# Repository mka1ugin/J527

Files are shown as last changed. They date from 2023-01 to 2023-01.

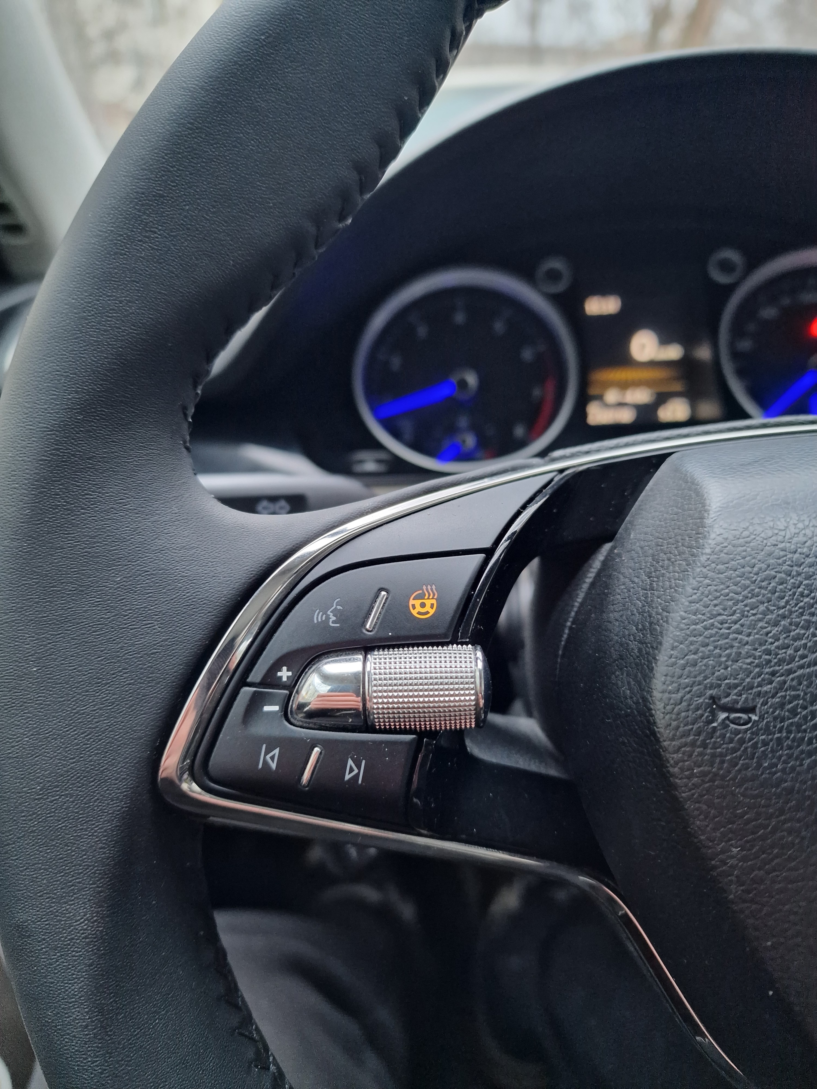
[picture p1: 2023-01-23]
result.jpg

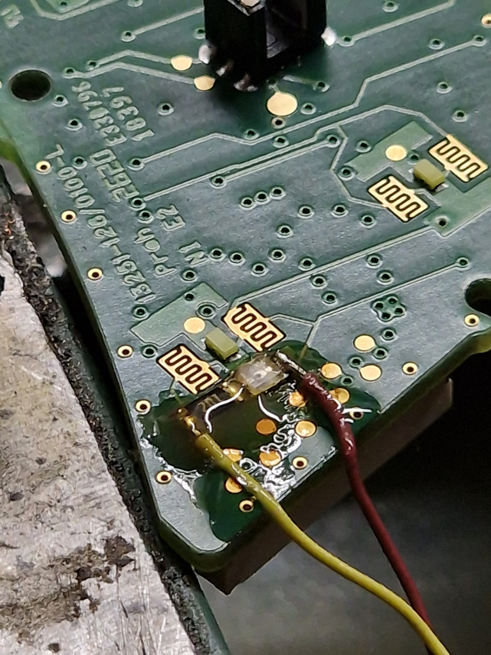
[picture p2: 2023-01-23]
heat_indication_led.jpg

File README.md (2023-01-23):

# J527
## Дополнительный контроллер для подрулевого блока 5K0953569, реализующий работу кнопки ассистентов, круиза и обогрева руля

Руль от Skoda 2021 5E3419093CVKH оборудован обогревом руля, кнопкой включения и выключения подогрева, а также кнопками быстрого вызова ассистентов и установки скорости круиз-контроля. Руль дооснащён LIN-LIN конвертером https://github.com/mka1ugin/LIN_MFSW_Adapter и установлен на VW Passat B6.
Подрулевой блок 5K0953569T доработан путём установки дополнительных шлейфов обогрева руля от блока 5Q1953569B. 
Контроллер выполнен на МК STM32F103C8T6 и реализует следующие функции:
* Управление работой обогрева руля
* Эмуляция нажатия кнопки быстрого вызова ассистентов
* Эмуляция нажатия кнопки задания скорости круиз-контроля

## Контроль обогрева руля

Сигнал нажатия кнопки обогрева руля отслеживается через LIN-шину. Нажатие кнопки включает и выключает обогрев руля. Питание на обогрев подаётся с клеммы 15 и только при включенном зажигании. Кроме того, контроллер отслеживает напряжение питания и работа возможна только при напряжении выше 12.5 В (настраивается в прошивке), т.е. при работающем двигателе. Силовой ключ VN7010A взят из блока 5Q1953569B.
Контроллер оборудован FRAM-памятью FM24CL16, в которую записывается каждое изменение состояния обогрева. Таким образом, если машина была заглушена со включенным обогревом, при следующем запуске двигателя обогрев будет включен автоматически.

## Эмуляция нажатия кнопок

Контроллер управляет двумя герконовыми реле серии EDR3. Их контактные группы включены параллельно штатным кнопкам "SET" круиз-контроля и кнопке быстрого вызова ассистентов. Контакты геркона дублируют состояние соответствующих кнопок на руле.

## Реализация

Контроллер выполнен на односторонней плате размером 50x47.5 мм и соединяется с блоком подрулевых переключателей двумя разъёмами: трёхконтактный - питание 12В и LIN-шина, и пятиконтактный - эмуляция нажатия кнопок. Также контроллер имеет два силовых четырёхконтактных разъёма - вход силового питания и выход на шлейф обогрева.render3

## Видео работы:
<p align="center">
  <a href="https://youtu.be/Oqg4uzVC5qI">youtube
</p>

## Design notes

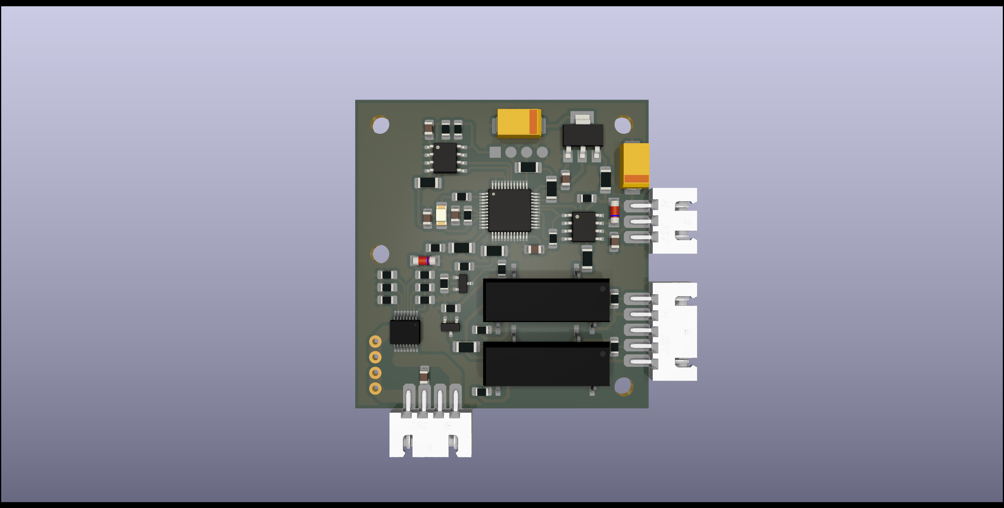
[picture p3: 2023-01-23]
HW/J527/pcb_render.png

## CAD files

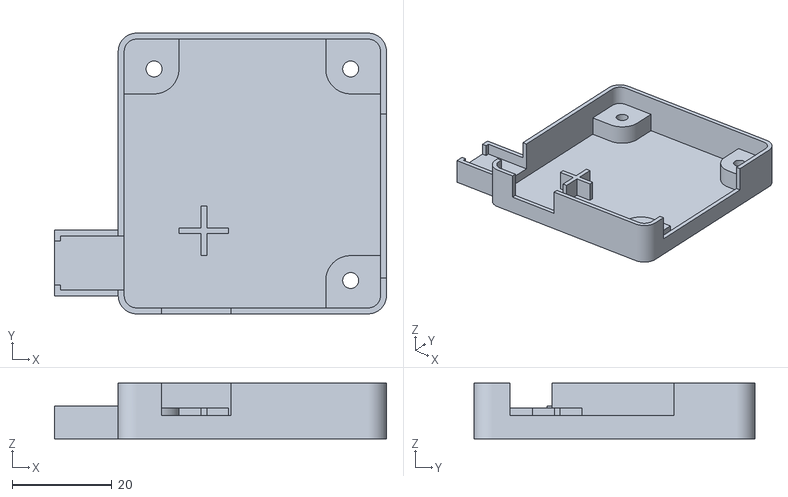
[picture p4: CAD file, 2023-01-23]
HW/J527/3Dprint/Основание.stl
66.7 x 56.4 x 11.2

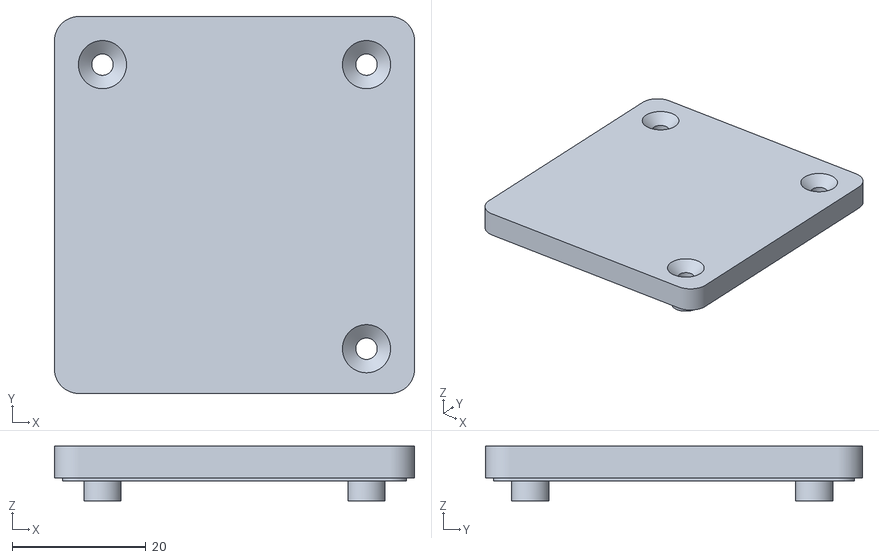
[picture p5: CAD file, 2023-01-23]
HW/J527/3Dprint/Крышка.stl
53.9 x 56.4 x 8.20

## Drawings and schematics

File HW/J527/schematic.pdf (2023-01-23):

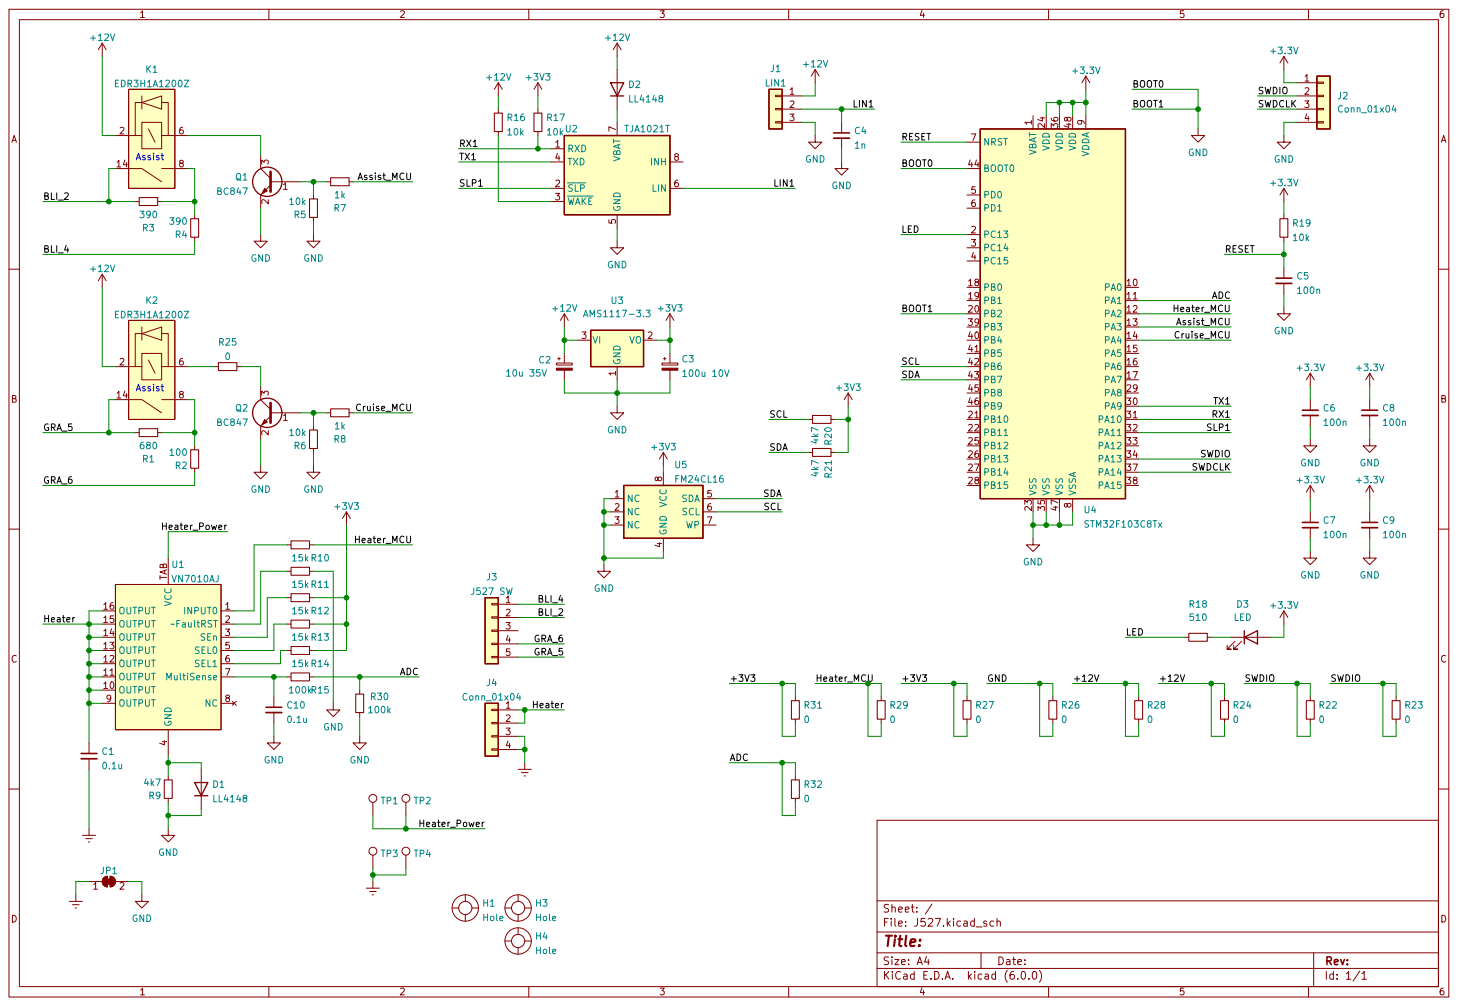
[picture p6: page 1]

1 PA0 10 PA1 11 PA2 12 PA3 13 PA4 14 PA5 15 PA6 16 PA7 17 PB0 18 PB1 19 PC13 2 PB2 20 PB10 21 PB11 22 VSS 23 VDD 24 PB12 25 PB13 26 PB14 27 PB15 28 PA8 29 PC14 3 PA9 30 PA10 31 PA11 32 PA12 33 PA13 34 VSS 35 VDD 36 PA14 37 PA15 38 PB3 39 PC15 4 PB4 40 PB5 41 PB6 42 PB7 43 BOOT0 44 PB8 45 PB9 46 VSS 47 VDD 48 PD0 5 PD1 6 NRST 7 VSSA

4 SEL0 5 SEL1 6 MultiSense 7 NC 8 OUTPUT 9 VCC TABU1VN7010AJ GND

4 SDA 5 SCL 6 WP 7 VCC

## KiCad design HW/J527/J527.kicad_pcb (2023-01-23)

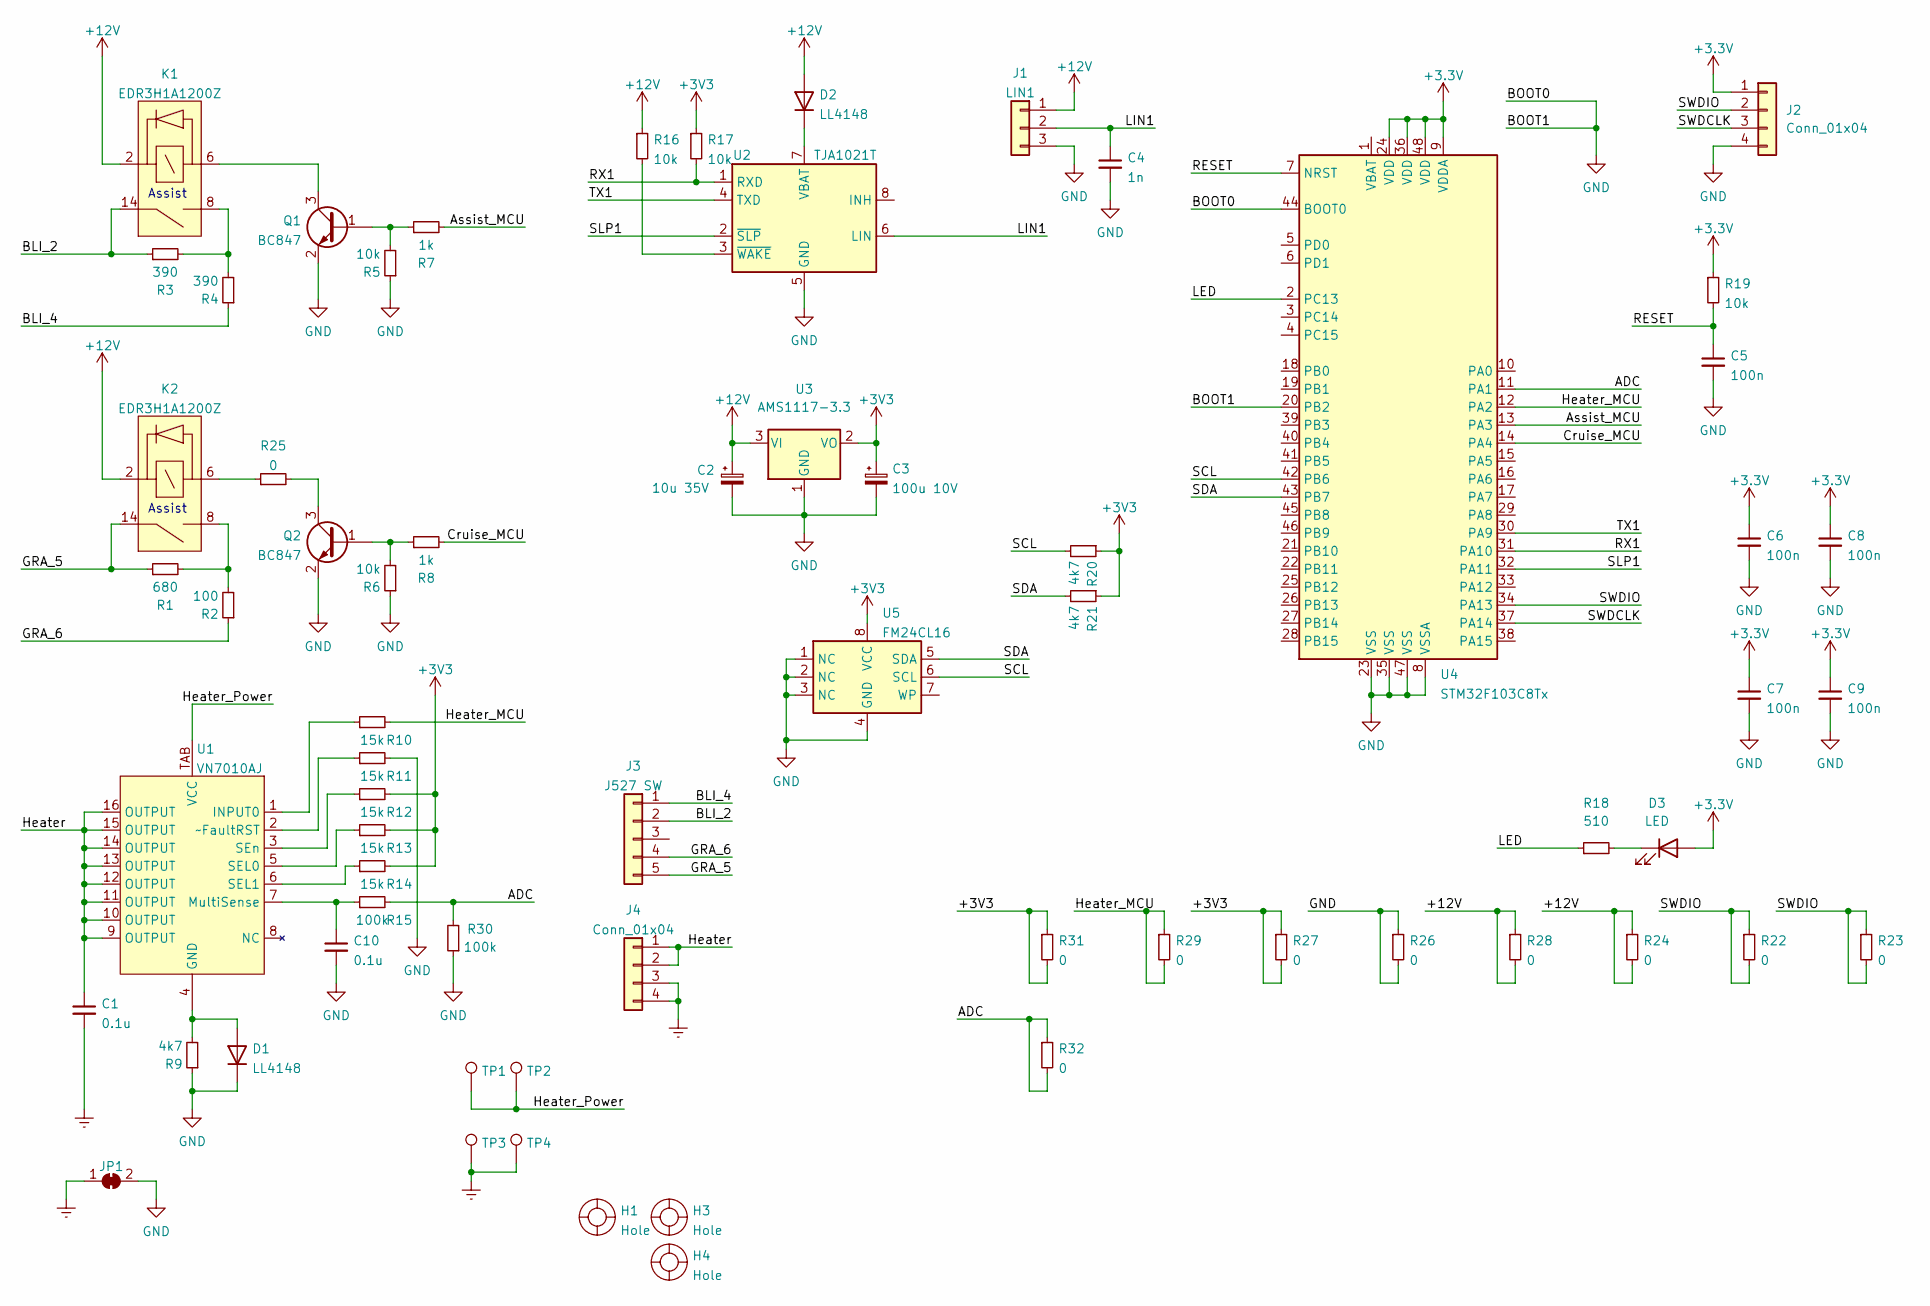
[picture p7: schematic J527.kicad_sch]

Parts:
C1, C10: 0.1u; C_0805_2012Metric_Pad1.18x1.45mm_HandSolder
C2: 10u 35V; CP_EIA-7343-31_Kemet-D_Pad2.25x2.55mm_HandSolder
C3: 100u 10V; CP_EIA-7343-31_Kemet-D_Pad2.25x2.55mm_HandSolder
C4: 1n; C_0805_2012Metric_Pad1.18x1.45mm_HandSolder
C5, C6, C7, C8, C9: 100n; C_0805_2012Metric_Pad1.18x1.45mm_HandSolder
D1, D2: LL4148; D_MiniMELF
D3: LED; LED_1206_3216Metric_Pad1.42x1.75mm_HandSolder
H1, H3, H4: Hole; Hole 3 mm
J1: LIN1; B3B-AM
J2: Conn_01x04; SMD_SWD_Connector
J3: J527 SW; B5B-AM
J4: Conn_01x04; B4B-AM
JP1: SolderJumper_2_Bridged; SolderJumper-2_P1.3mm_Bridged_Pad1.0x1.5mm
K1, K2: EDR3H1A1200Z
Q1, Q2: BC847; SOT-23
R1: 680; R_0805_2012Metric_Pad1.20x1.40mm_HandSolder
R2: 100; R_0805_2012Metric_Pad1.20x1.40mm_HandSolder
R3, R4: 390; R_0805_2012Metric_Pad1.20x1.40mm_HandSolder
R5, R6, R16, R17, R19: 10k; R_0805_2012Metric_Pad1.20x1.40mm_HandSolder
R7, R8: 1k; R_0805_2012Metric_Pad1.20x1.40mm_HandSolder
R9, R20, R21: 4k7; R_0805_2012Metric_Pad1.20x1.40mm_HandSolder
R10, R11, R12, R13, R14: 15k; R_0805_2012Metric_Pad1.20x1.40mm_HandSolder
R15, R30: 100k; R_0805_2012Metric_Pad1.20x1.40mm_HandSolder
R18: 510; R_0805_2012Metric_Pad1.20x1.40mm_HandSolder
R22, R23, R24, R25, R26, R27, R28, R29, R31, R32: 0; R_1206_3216Metric_Pad1.30x1.75mm_HandSolder
TP1, TP2: Heat_PW; TestPoint_THTPad_D2.0mm_Drill1.0mm
TP3, TP4: GND; TestPoint_THTPad_D2.0mm_Drill1.0mm
U1: VN7010AJ; PowerSSO-16
U2: TJA1021T; SOIC-8_3.9x4.9mm_P1.27mm
U3: AMS1117-3.3; SOT-223-3_TabPin2
U4: STM32F103C8Tx; LQFP-48_7x7mm_P0.5mm
U5: FM24CL16; SO-8_3.9x4.9mm_P1.27mm

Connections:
+12V: C2.1, D2.2 (A), J1.1, K1.2, K2.2, R16.1, R24.1, R24.2, R28.1, R28.2, U3.3 (VI)
/ADC: R15.2, R30.2, R32.1, R32.2, U4.11 (PA1)
/Assist_MCU: R7.2, U4.13 (PA3)
/BLI_2: J3.2, K1.14, R3.1
/BLI_4: J3.1, R4.1
/Cruise_MCU: R8.2, U4.14 (PA4)
/GRA_5: J3.5, K2.14, R1.1
/GRA_6: J3.4, R2.1
/Heater: C1.1, J4.1, J4.2, U1.9 (OUTPUT), U1.10 (OUTPUT), U1.11 (OUTPUT), U1.12 (OUTPUT), U1.13 (OUTPUT), U1.14 (OUTPUT), U1.15 (OUTPUT), U1.16 (OUTPUT)
/Heater_MCU: R10.2, R29.1, R29.2, U4.12 (PA2)
/Heater_Power: TP1.1, TP2.1, U1.TAB (VCC)
/LED: R18.1, U4.2 (PC13)
/LIN1: C4.1, J1.2, U2.6 (LIN)
/RESET: C5.1, R19.2, U4.7 (NRST)
/RX1: R17.2, U2.1 (RXD), U4.31 (PA10)
/SCL: R20.2, U4.42 (PB6), U5.6 (SCL)
/SDA: R21.2, U4.43 (PB7), U5.5 (SDA)
/SLP1: U2.2 (~SLP), U4.32 (PA11)
/SWDCLK: J2.3, U4.37 (PA14)
/SWDIO: J2.2, R22.1, R22.2, R23.1, R23.2, U4.34 (PA13)
/TX1: U2.4 (TXD), U4.30 (PA9)
Earth: C1.2, J4.3, J4.4, JP1.1 (A), TP3.1, TP4.1
GND: C2.2, C3.2, C4.2, C5.2, C6.2, C7.2, C8.2, C9.2, C10.2, D1.1 (K), J1.3, J2.4, JP1.2 (B), Q1.2 (E), Q2.2 (E), R5.1, R6.1, R9.1, R11.2, R26.1, R26.2, R30.1, U2.5 (GND), U3.1 (GND), U4.8 (VSSA), U4.20 (PB2), U4.23 (VSS), U4.35 (VSS), U4.44 (BOOT0), U4.47 (VSS), U5.1 (NC), U5.2 (NC), U5.3 (NC), U5.4 (GND)
unnamed: C10.1, R15.1, U1.7 (MultiSense)
unnamed: D1.2 (A), R9.2, U1.4 (GND)
unnamed: D2.1 (K), U2.7 (VBAT)
unnamed: D3.1 (K), R18.2
unnamed: K1.6, Q1.3 (C)
unnamed: K1.8, R3.2, R4.2
unnamed: K2.6, R25.1
unnamed: K2.8, R1.2, R2.2
unnamed: Q1.1 (B), R5.2, R7.1
unnamed: Q2.1 (B), R6.2, R8.1
unnamed: Q2.3 (C), R25.2
unnamed: R10.1, U1.1 (INPUT0)
unnamed: R11.1, U1.2 (~FaultRST)
unnamed: R12.1, U1.3 (SEn)
unnamed: R13.1, U1.5 (SEL0)
unnamed: R14.1, U1.6 (SEL1)
unnamed: R16.2, U2.3 (~WAKE)

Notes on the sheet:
Assist

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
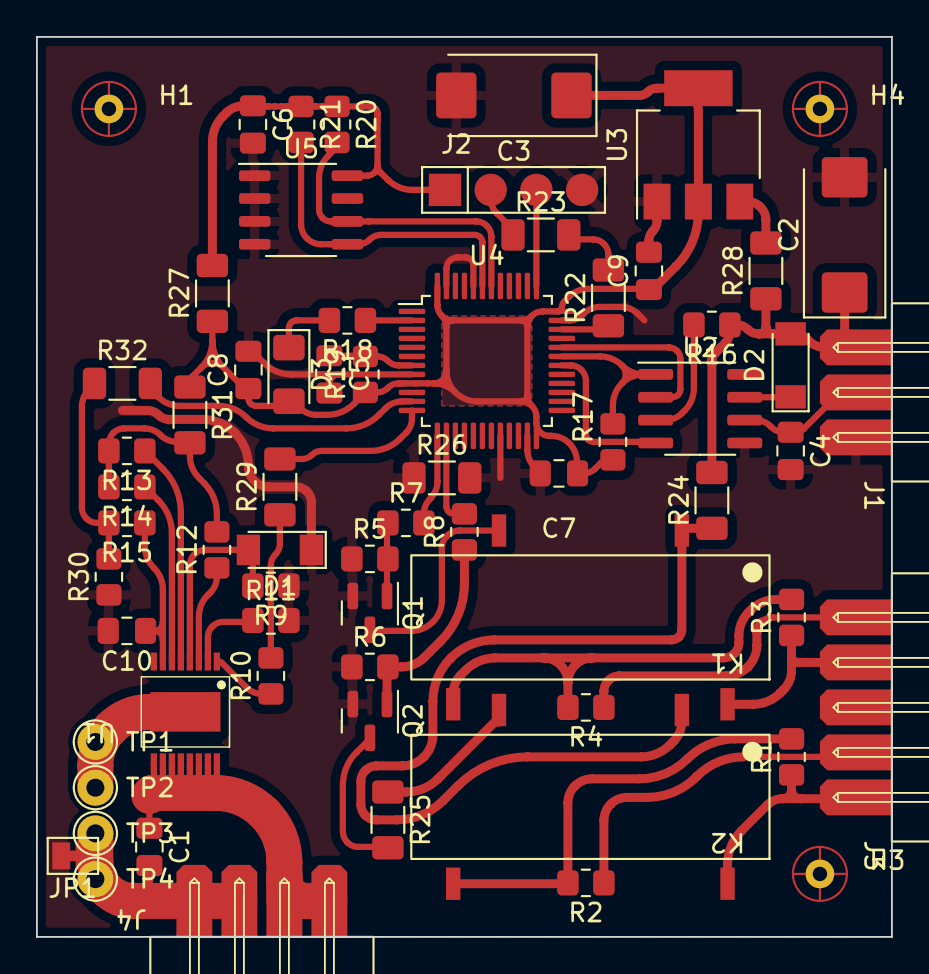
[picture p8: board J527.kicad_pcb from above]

Board: 2 copper layers, 47.5 x 50.0 mm, 66 parts (0 on the bottom side), 41 nets.

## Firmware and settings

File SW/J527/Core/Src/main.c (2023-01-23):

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
/* Includes ------------------------------------------------------------------*/
#include "main.h"

ADC_HandleTypeDef hadc1;
DMA_HandleTypeDef hdma_adc1;

I2C_HandleTypeDef hi2c1;

IWDG_HandleTypeDef hiwdg;

TIM_HandleTypeDef htim3;

UART_HandleTypeDef huart1;

/* USER CODE BEGIN PV */
uint16_t adcData[1];
float voltage = 0.0;

uint8_t voltageState = 0;
uint8_t assistState = 0;
uint8_t cruiseState = 0;
uint8_t heaterState = 0;
uint8_t heaterPreviousState = 0;

uint8_t measurement = 0;
uint16_t adcValues[MEAS_NUM];

uint8_t heaterRequest = 0;

uint8_t buttonData[9];

uint8_t readData[1];
uint8_t writeData[1];

uint16_t devAddr = (0x50 << 1);
uint16_t memAddr = 0x0000;
HAL_StatusTypeDef status;
/* USER CODE END PV */

void SystemClock_Config(void);
static void MX_GPIO_Init(void);
static void MX_DMA_Init(void);
static void MX_ADC1_Init(void);
static void MX_I2C1_Init(void);
static void MX_USART1_UART_Init(void);
static void MX_TIM3_Init(void);
static void MX_IWDG_Init(void);
/* USER CODE BEGIN PFP */
void writePins(void);
/* USER CODE END PFP */

/* USER CODE BEGIN 0 */
LIN_State slaveState = LIN_RECEIVING_BREAK;
/* USER CODE END 0 */

/**
  * @brief  The application entry point.
  * @retval int
  */
int main(void)
{
  /* MCU Configuration--------------------------------------------------------*/

  /* Reset of all peripherals, Initializes the Flash interface and the Systick. */
  HAL_Init();

  /* Configure the system clock */
  SystemClock_Config();

  /* Initialize all configured peripherals */
  MX_GPIO_Init();
  MX_DMA_Init();
  MX_ADC1_Init();
  MX_I2C1_Init();
  MX_USART1_UART_Init();
  MX_TIM3_Init();
  MX_IWDG_Init();
  /* USER CODE BEGIN 2 */
	HAL_TIM_Base_Start_IT(&htim3);
	HAL_ADC_Start_DMA(&hadc1, (uint32_t*)adcData, 1);
	
	HAL_GPIO_WritePin(USART1_SLP_GPIO_Port, USART1_SLP_Pin, GPIO_PIN_SET);
	
	__HAL_UART_ENABLE_IT(&huart1, UART_IT_LBD);
	
	uint8_t tempReadData[1];
	HAL_I2C_Mem_Read(&hi2c1, devAddr, memAddr, I2C_MEMADD_SIZE_16BIT, (uint8_t*)tempReadData, 1, HAL_MAX_DELAY);
	heaterRequest = tempReadData[0];

  /* USER CODE END 2 */

  /* Infinite loop */
  /* USER CODE BEGIN WHILE */
  while (1)
  {
	writePins();		
    /* USER CODE END WHILE */

    /* USER CODE BEGIN 3 */
  }
  /* USER CODE END 3 */
}

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
/* USER CODE BEGIN 4 */
void HAL_ADC_ConvCpltCallback(ADC_HandleTypeDef* hadc)
{
  if(hadc->Instance == ADC1)
  {
		adcValues[measurement] = HAL_ADC_GetValue(&hadc1);
		
		if (measurement < MEAS_NUM - 1)
		{
			measurement++;
		}
		
		else			
		{
			uint32_t sum = 0;
			for (int i = 0; i < MEAS_NUM; i++)
			{
				sum += (uint32_t)adcValues[i];				
			}
			voltage = sum / MEAS_NUM * 0.0064 - 1.3651;
			measurement = 0;
		}			
			if (voltage > enableVoltage)
				{
					voltageState = 1;
				}
				
			if (voltage < disableVoltage)
			{
				voltageState = 0;
			}
		}
  }

void HAL_TIM_PeriodElapsedCallback(TIM_HandleTypeDef *htim)
{
    if (htim->Instance == TIM3)
    {
        HAL_ADC_Start_DMA(&hadc1, (uint32_t*)adcData, 1);
    }
}

void writePins(void)
{
	if (cruiseState)
	{
		HAL_GPIO_WritePin(Cruise_GPIO_Port, Cruise_Pin, GPIO_PIN_SET);
	} else
	{
		HAL_GPIO_WritePin(Cruise_GPIO_Port, Cruise_Pin, GPIO_PIN_RESET);
	}
	
	if (assistState)
	{
		HAL_GPIO_WritePin(Assist_GPIO_Port, Assist_Pin, GPIO_PIN_SET);
	} else
	{
		HAL_GPIO_WritePin(Assist_GPIO_Port, Assist_Pin, GPIO_PIN_RESET);
	}
	
	if (heaterRequest && voltageState)
	{
		HAL_GPIO_WritePin(Heater_GPIO_Port, Heater_Pin, GPIO_PIN_SET);
	} else
	{
		HAL_GPIO_WritePin(Heater_GPIO_Port, Heater_Pin, GPIO_PIN_RESET);
	}
}

void decodeButtonData(void)
{
	switch(buttonData[1]) {
		case CRUISE_ID: cruiseState = 1; 
										assistState = 0;
										heaterPreviousState = heaterState;
										heaterState = 0;
										break;
		case ASSIST_ID: cruiseState = 0;
										assistState = 1;
										heaterPreviousState = heaterState;
										heaterState = 0;
										break;
		case HEATER_ID: cruiseState = 0; 
										assistState = 0;
										heaterPreviousState = heaterState;
										heaterState = 1;
										break;
		default: 				cruiseState = 0;
										assistState = 0;
										heaterPreviousState = heaterState;
										heaterState = 0;
										break;
	}
	
	if (heaterPreviousState == 1 && heaterState == 0)
	{
		if (heaterRequest == 1) { heaterRequest = 0; }
		else { heaterRequest = 1; }
		
		uint8_t tempWriteData[1];
		tempWriteData[0] = heaterRequest;
		HAL_I2C_Mem_Write(&hi2c1, devAddr, memAddr, I2C_MEMADD_SIZE_16BIT, (uint8_t*)tempWriteData, 1, HAL_MAX_DELAY);
		for(;;) {
        status = HAL_I2C_IsDeviceReady(&hi2c1, devAddr, 1, HAL_MAX_DELAY);
        if(status == HAL_OK)
            break;
						}
	}
}
/* USER CODE END 4 */
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


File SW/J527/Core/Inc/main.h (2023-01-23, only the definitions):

#define LED_Pin GPIO_PIN_13
#define LED_GPIO_Port GPIOC
#define Voltage_ADC_Pin GPIO_PIN_1
#define Voltage_ADC_GPIO_Port GPIOA
#define Heater_Pin GPIO_PIN_2
#define Heater_GPIO_Port GPIOA
#define Assist_Pin GPIO_PIN_3
#define Assist_GPIO_Port GPIOA
#define Cruise_Pin GPIO_PIN_4
#define Cruise_GPIO_Port GPIOA
#define USART1_SLP_Pin GPIO_PIN_11
#define USART1_SLP_GPIO_Port GPIOA
#define enableVoltage 12.5
#define disableVoltage 12.0
#define MEAS_NUM	255
#define LIN_ID 		0x8E
#define CRUISE_ID	0x74
#define ASSIST_ID	0x0C
#define HEATER_ID	0x25
#define LIN_SYNC_BYTE	0x55

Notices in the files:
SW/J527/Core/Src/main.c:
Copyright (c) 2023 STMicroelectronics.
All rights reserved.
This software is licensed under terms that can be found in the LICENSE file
